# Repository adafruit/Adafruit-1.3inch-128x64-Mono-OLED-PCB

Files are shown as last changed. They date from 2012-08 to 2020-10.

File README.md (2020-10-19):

# PCB for the Adafruit 128x64 I2C/SPI 1.3" OLED breakout board

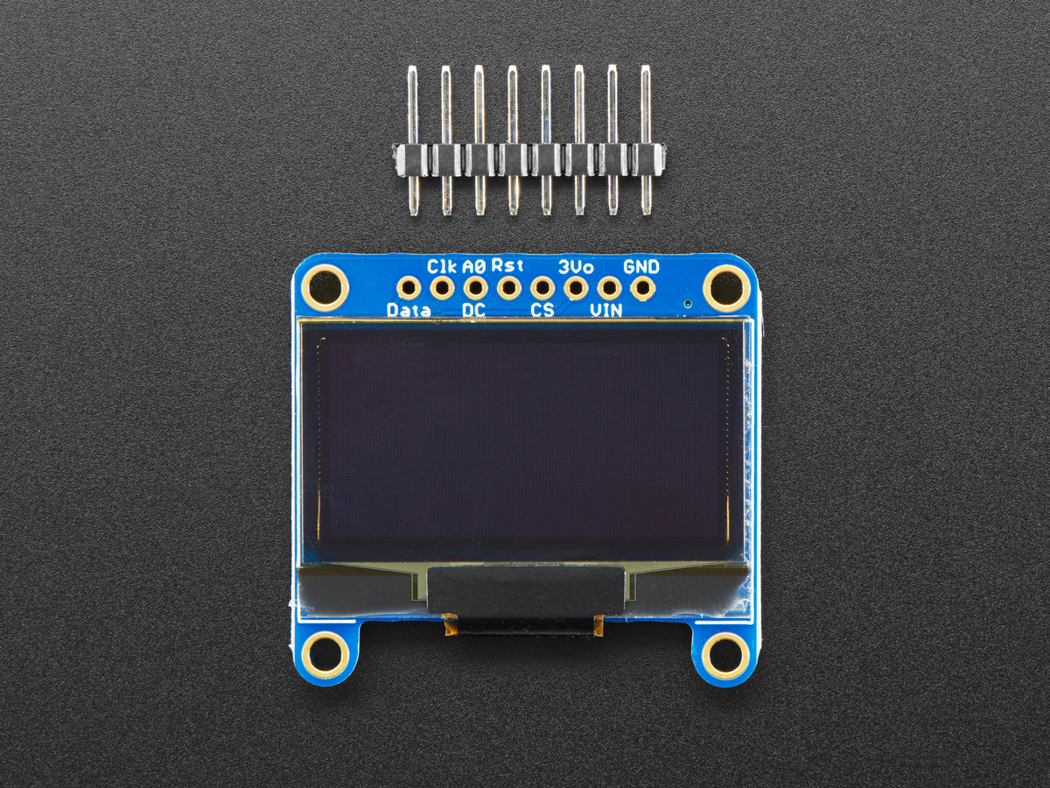
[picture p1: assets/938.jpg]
<a href="http://www.adafruit.com/products/938"><br/>
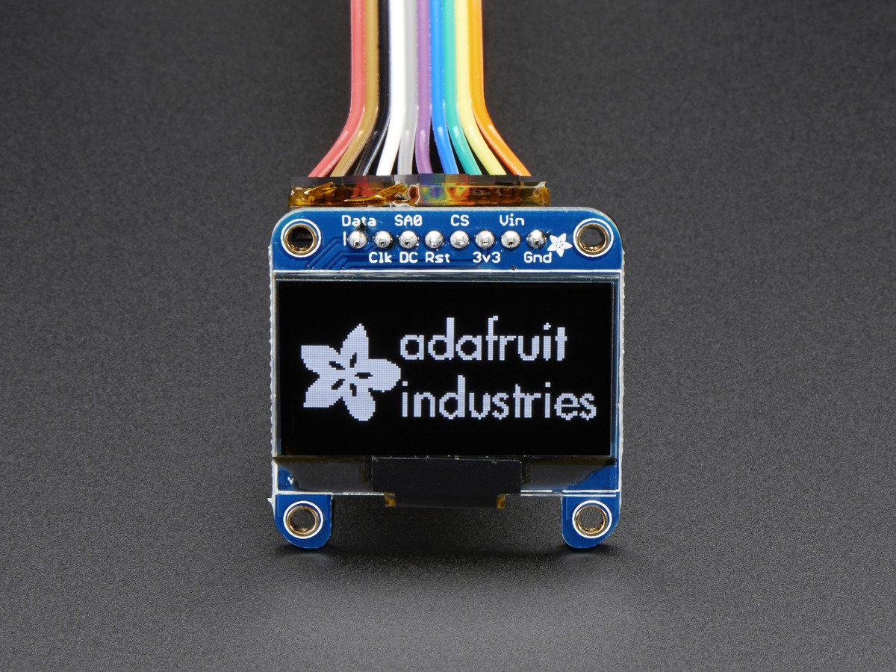
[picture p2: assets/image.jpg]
<a href="http://www.adafruit.com/products/938"><br/>
  Click here to purchase one from the Adafruit shop</a>

__Format is EagleCAD schematic and board layout__

These displays are small, only about 1.3" diagonal, but very readable due to the high contrast of an OLED display. This display is made of 128x64 individual white OLED pixels, each one is turned on or off by the controller chip. Because the display makes its own light, no backlight is required. This reduces the power required to run the OLED and is why the display has such high contrast; we really like this miniature display for its crispness!

The driver chip, SSD1306 can communicate in two ways: I2C or SPI. The OLED itself require a 3.3V power supply and 3.3V logic levels for communication, but we include a 3.3V regulator and all pins are fully level shifted so you can use with 5V devices!

We've updated the design to add auto-reset circuitry so that the reset pin is optional. The default interface is now I2C not SPI - since it speaks I2C you can easily connect it up with just two wires (plus power and ground!).  We've even included SparkFun qwiic compatible STEMMA QT connectors for the I2C bus so you don't even need to solder! 

The power requirements depend a little on how much of the display is lit but on average the display uses about 40mA from the 3.3V supply. Built into the OLED driver is a simple switch-cap charge pump that turns 3.3v-5v into a high voltage drive for the OLEDs.

[We have a detailed tutorial and example code in the form of an Arduino library](http://learn.adafruit.com/monochrome-oled-breakouts) for text and graphics. You'll need a microcontroller with more than 1K of RAM since the display must be buffered. The library can print text, bitmaps, pixels, rectangles, circles and lines. It uses 1K of RAM since it needs to buffer the entire display but its very fast! The code is simple to adapt to any other microcontroller.

## License
Adafruit invests time and resources providing this open source design,
please support Adafruit and open-source hardware by purchasing
products from Adafruit!

Designed by Adafruit Industries.
Creative Commons Attribution, Share-Alike license, check license.txt for more information
All text above must be included in any redistribution

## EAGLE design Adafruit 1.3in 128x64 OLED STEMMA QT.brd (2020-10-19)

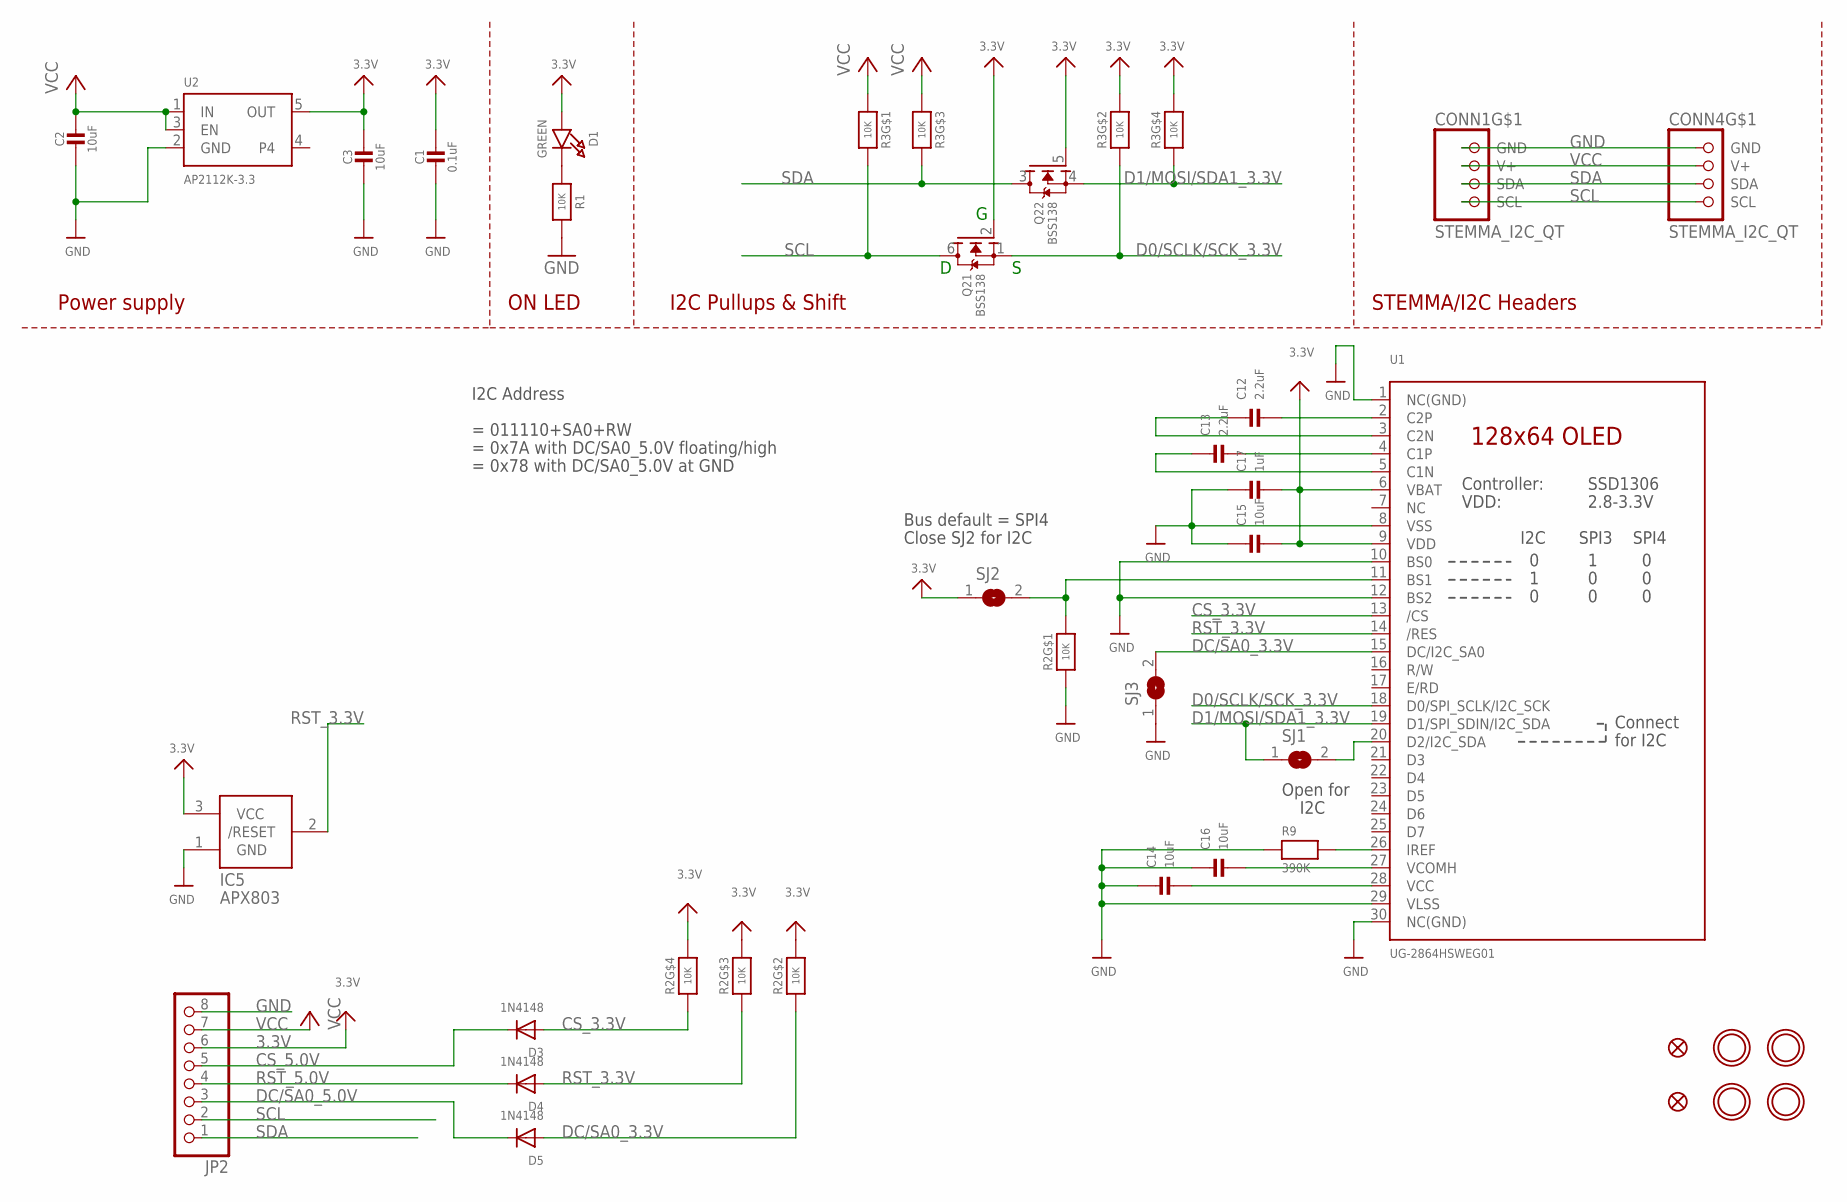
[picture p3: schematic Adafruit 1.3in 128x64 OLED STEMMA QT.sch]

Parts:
C1: 0.1uF; 0603-NO
C2, C3, C14, C15, C16: 10uF; 0805-NO
C12, C13: 2.2uF; 0805-NO
C17: 1uF; 0603-NO
CONN1, CONN4: STEMMA_I2C_QT; JST_SH4
D1: GREEN; CHIPLED_0603_NOOUTLINE
D3, D4, D5: 1N4148; SOD-323
FID3, FID4: FIDUCIAL_1MM
IC5: APX803; SOT23
JP2: HEADER-1X870MIL; 1X08_ROUND_70
Q2: BSS138; SOT363
R1: 10K; 0603-NO
R2, R3: 10K; RESPACK_4X0603
R9: 390K; 0603-NO
SJ1, SJ2: SOLDERJUMPERCLOSED; SOLDERJUMPER_CLOSEDWIRE
SJ3: SOLDERJUMPER; SOLDERJUMPER_ARROW_NOPASTE
U1: UG-2864HSWEG01; UG-2864HSWEG01_1.3_WRAPAROUND
U2: AP2112K-3.3; SOT23-5
U$1, U$17, U$19, U$21: MOUNTINGHOLE2.5; MOUNTINGHOLE_2.5_PLATED

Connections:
3.3V: C1.1, C3.1, C15.2, C17.2, D1.A, IC5.3 (VCC), JP2.6, Q2.2 (G), Q2.5 (G), R2.5 (2), R2.6 (2), R2.7 (2), R3.2 (1), R3.4 (1), SJ2.1, U1.6 (VBAT), U1.9 (VDD), U2.5 (OUT)
CS_3.3V: D3.A, R2.4 (1), U1.13 (/CS)
CS_5.0V: D3.C, JP2.5
D0/SCLK/SCK_3.3V: Q2.1 (S), R3.7 (2), U1.18 (D0/SPI_SCLK/I2C_SCK)
D1/MOSI/SDA1_3.3V: Q2.4 (S), R3.5 (2), SJ1.1, U1.19 (D1/SPI_SDIN/I2C_SDA)
DC/SA0_3.3V: D5.A, R2.2 (1), SJ3.2, U1.15 (DC/I2C_SA0)
DC/SA0_5.0V: D5.C, JP2.3
GND: C1.2, C2.2, C3.2, C14.1, C15.1, C16.1, C17.1, CONN1.1 (GND), CONN4.1 (GND), IC5.1 (GND), JP2.8, R1.2, R2.1, R9.1, SJ3.1, U1.1 (NC(GND)), U1.8 (VSS), U1.10 (BS0), U1.12 (BS2), U1.29 (VLSS), U1.30 (NC(GND)), U2.2 (GND)
unnamed: D1.C, R1.1
unnamed: R2.8 (2), SJ2.2, U1.11 (BS1)
unnamed: R9.2, U1.26 (IREF)
unnamed: C12.2, U1.2 (C2P)
unnamed: C12.1, U1.3 (C2N)
unnamed: C13.2, U1.4 (C1P)
unnamed: C13.1, U1.5 (C1N)
unnamed: C14.2, U1.28 (VCC)
unnamed: C16.2, U1.27 (VCOMH)
unnamed: SJ1.2, U1.20 (D2/I2C_SDA)
RST_3.3V: D4.A, IC5.2 (/RESET), R2.3 (1), U1.14 (/RES)
RST_5.0V: D4.C, JP2.4
SCL: CONN1.4 (SCL), CONN4.4 (SCL), JP2.2, Q2.6 (D), R3.8 (2)
SDA: CONN1.3 (SDA), CONN4.3 (SDA), JP2.1, Q2.3 (D), R3.6 (2)
VCC: C2.1, CONN1.2 (V+), CONN4.2 (V+), JP2.7, R3.1, R3.3 (1), U2.1 (IN), U2.3 (EN)

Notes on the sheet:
I2C Pullups & Shift
STEMMA/I2C Headers
ON LED
Power supply
Bus default = SPI4
Close SJ2 for I2C
= 011110+SA0+RW
= 0x7A with DC/SA0_5.0V floating/high
= 0x78 with DC/SA0_5.0V at GND
I2C Address
Open for
I2C

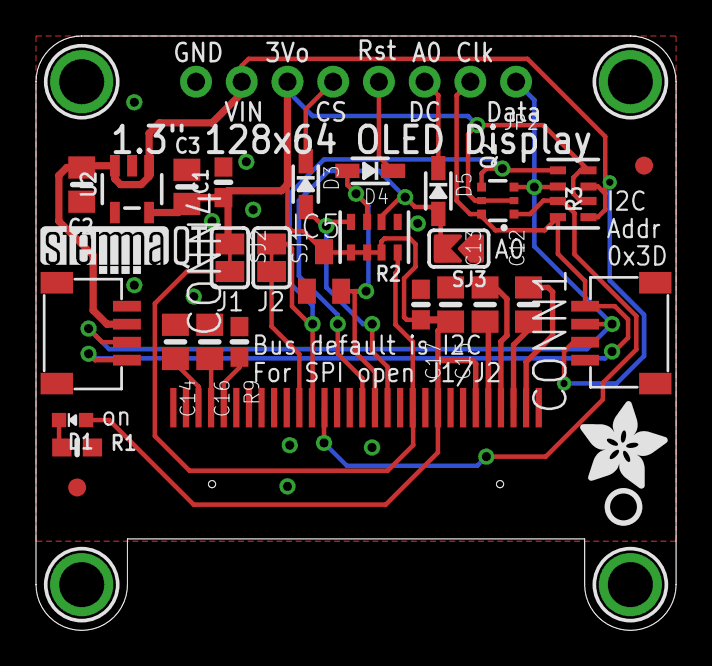
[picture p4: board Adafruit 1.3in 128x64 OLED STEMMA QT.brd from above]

Board: 2 copper layers, 35.6 x 33.0 mm, 36 parts (1 on the bottom side), 23 nets.

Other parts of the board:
U$8: ADAFRUIT_5MM
U$25: PCBFEAT-REV-040
U$31: STEMMAQT

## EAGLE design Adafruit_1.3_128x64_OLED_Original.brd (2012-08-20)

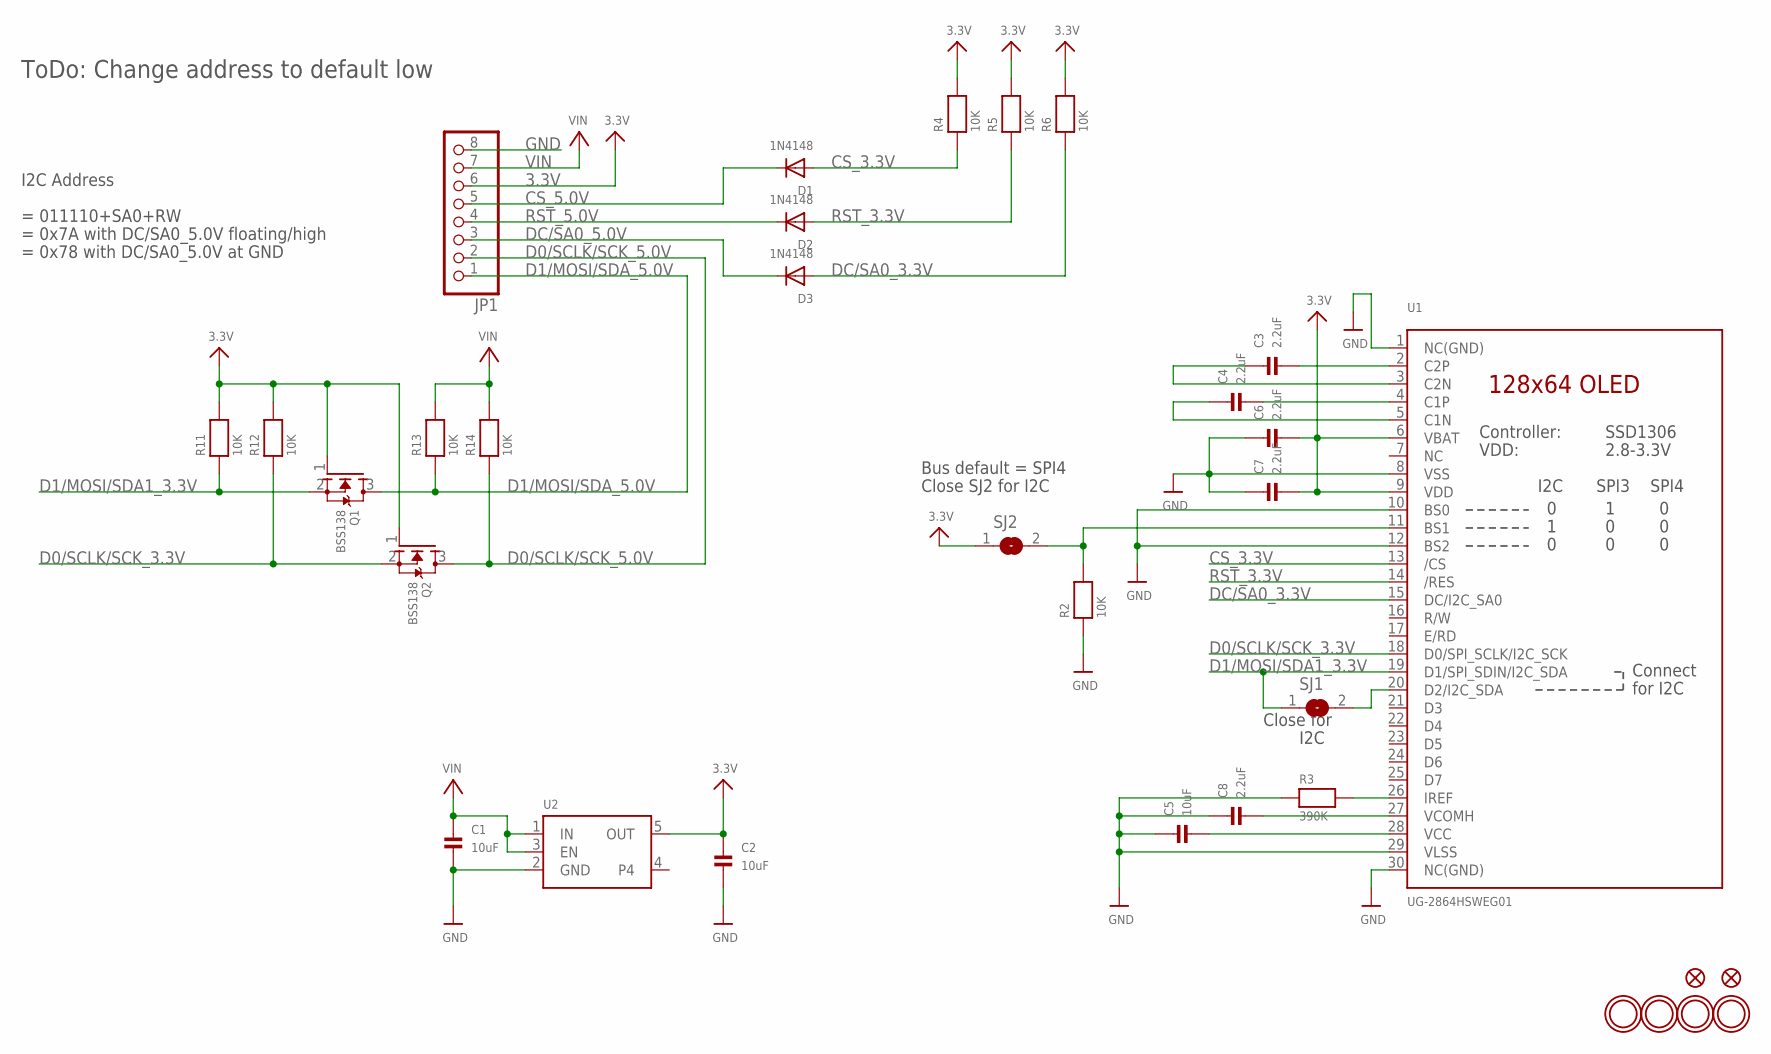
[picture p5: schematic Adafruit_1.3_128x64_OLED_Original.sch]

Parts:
C1, C2, C5: 10uF; 0805
C3, C4, C6, C7, C8: 2.2uF; 0805
D1, D2, D3: 1N4148; SOD-323
FID1, FID2: FIDUCIAL""; FIDUCIAL_1MM
JP1: HEADER-1X870MIL; 1X08_ROUND_70
Q1, Q2: BSS138; SOT23-WIDE
R2, R4, R5, R6, R11, R12, R13, R14: 10K; 0805
R3: 390K; 0805
SJ1, SJ2: SOLDERJUMPERREFLOW_NOPASTE; SOLDERJUMPER_REFLOW_NOPASTE
U1: UG-2864HSWEG01; UG-2864HSWEG01_1.3_WRAPAROUND
U2: VREG_SOT23-5; SOT23-5
U$23, U$24, U$25, U$26: MOUNTINGHOLE2.5; MOUNTINGHOLE_2.5_PLATED

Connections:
3.3V: C2.1, C6.2, C7.2, JP1.6, Q1.1 (G), Q2.1 (G), R4.2, R5.2, R6.2, R11.2, R12.2, SJ2.1, U1.6 (VBAT), U1.9 (VDD), U2.5 (OUT)
CS_3.3V: D1.A, R4.1, U1.13 (/CS)
CS_5.0V: D1.C, JP1.5
D0/SCLK/SCK_3.3V: Q2.2 (S), R12.1, U1.18 (D0/SPI_SCLK/I2C_SCK)
D0/SCLK/SCK_5.0V: JP1.2, Q2.3 (D), R14.1
D1/MOSI/SDA1_3.3V: Q1.2 (S), R11.1, SJ1.1, U1.19 (D1/SPI_SDIN/I2C_SDA)
D1/MOSI/SDA_5.0V: JP1.1, Q1.3 (D), R13.1
DC/SA0_3.3V: D3.A, R6.1, U1.15 (DC/I2C_SA0)
DC/SA0_5.0V: D3.C, JP1.3
GND: C1.2, C2.2, C5.1, C6.1, C7.1, C8.1, JP1.8, R2.1, R3.1, U1.1 (NC(GND)), U1.8 (VSS), U1.10 (BS0), U1.12 (BS2), U1.29 (VLSS), U1.30 (NC(GND)), U2.2 (GND)
unnamed: R2.2, SJ2.2, U1.11 (BS1)
unnamed: SJ1.2, U1.20 (D2/I2C_SDA)
unnamed: R3.2, U1.26 (IREF)
unnamed: C3.2, U1.2 (C2P)
unnamed: C3.1, U1.3 (C2N)
unnamed: C4.2, U1.4 (C1P)
unnamed: C4.1, U1.5 (C1N)
unnamed: C5.2, U1.28 (VCC)
unnamed: C8.2, U1.27 (VCOMH)
RST_3.3V: D2.A, R5.1, U1.14 (/RES)
RST_5.0V: D2.C, JP1.4
VIN: C1.1, JP1.7, R13.2, R14.2, U2.1 (IN), U2.3 (EN)

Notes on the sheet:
Bus default = SPI4
Close SJ2 for I2C
= 011110+SA0+RW
= 0x7A with DC/SA0_5.0V floating/high
= 0x78 with DC/SA0_5.0V at GND
I2C Address
ToDo: Change address to default low
Close for
I2C

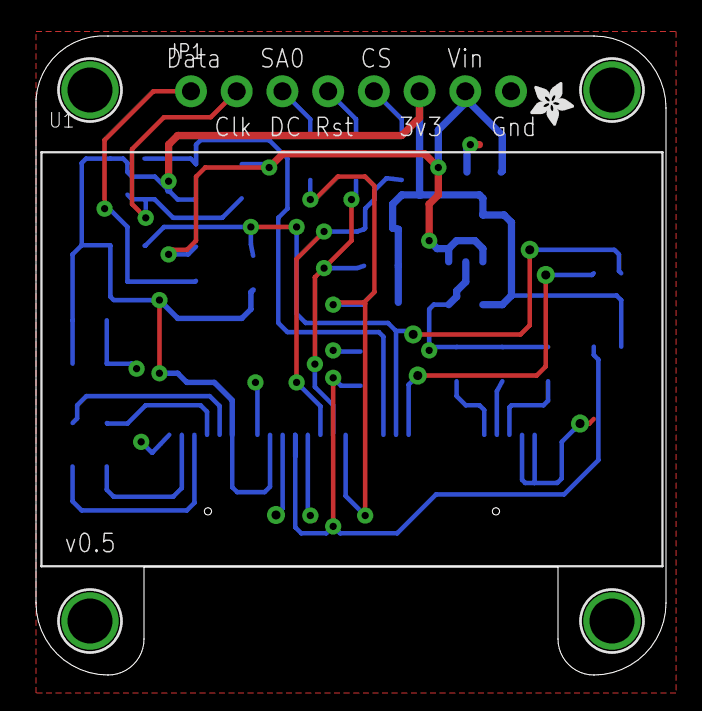
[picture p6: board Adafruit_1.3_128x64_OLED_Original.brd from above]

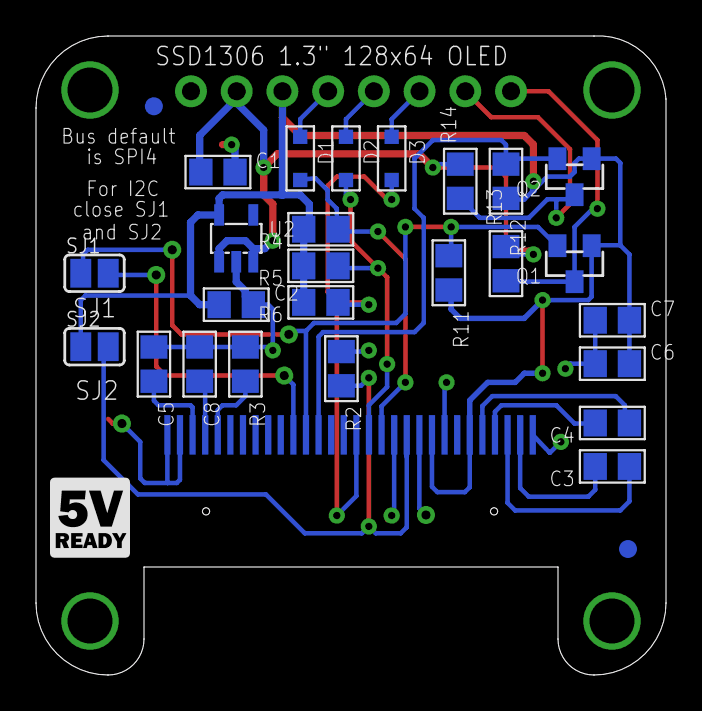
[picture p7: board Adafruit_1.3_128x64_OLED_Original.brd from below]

Board: 2 copper layers, 35.0 x 35.5 mm, 35 parts (28 on the bottom side), 22 nets.

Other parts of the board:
U$27: ADAFRUIT_2.5MM
U$28: LOGIC_5VREADY_5MM

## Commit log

2020-10-19 Add STEMMA board files.
    [Adafruit 1.3in 128x64 STEMMA QT.brd, Adafruit 1.3in 128x64 STEMMA QT.sch]
2020-10-19 Rename Adafruit 1.3in 128x64 STEMMA QT.brd to Adafruit 1.3in 128x64 OLED STEMMA QT.brd
    [Adafruit 1.3in 128x64 OLED STEMMA QT.brd]
2020-10-19 Rename Adafruit 1.3in 128x64 STEMMA QT.sch to Adafruit 1.3in 128x64 OLED STEMMA QT.sch
    [Adafruit 1.3in 128x64 OLED STEMMA QT.sch]

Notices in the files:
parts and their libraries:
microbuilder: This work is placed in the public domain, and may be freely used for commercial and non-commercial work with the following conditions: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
